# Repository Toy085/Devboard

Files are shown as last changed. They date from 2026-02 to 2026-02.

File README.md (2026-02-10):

# Info about the devboard

This devboard is bulit using the RP2040 microcontroller. It features a USB-C connector for power and data, and 16 Mbit of external flash storage.

### Images of the devboard:



### BOM:
Available in .csv format: [bom.csv](https://github.com/Toy085/Devboard/blob/main/bom.csv)

|  Item | Qty | Link |
| ---| --- | ---|
| 0.1uF Capacitor | 11 | https://jlcpcb.com/partdetail/1877-CL05B104KO5NNNC/C1525 |
| 1uF Capacitor | 2 | https://jlcpcb.com/partdetail/53938-CL05A105KA5NQNC/C52923 |
| 10uF Capacitor | 2 | https://jlcpcb.com/partdetail/20411-CL10A106KP8NNNC/C19702 |
| 33pF Capacitor | 2 | https://jlcpcb.com/partdetail/1914-0402CG330J500NT/C1562 |
| Male USB C Header | 1 | https://jlcpcb.com/partdetail/Korean_HropartsElec-TYPE_C_31_M12/C165948 |
| 1x20 pin header | 2 | https://jlcpcb.com/partdetail/51993-2_54_1_20PStraightpin/C50981 |
| 1x3 pin header | 1 | https://jlcpcb.com/partdetail/50265-2_54_13PPin/C49257 |
| RP2040 | 1 | https://jlcpcb.com/partdetail/RaspberryPi-RP2040/C2040 |
| Button | 1 | https://jlcpcb.com/partdetail/XUNPU-TS_1088AR02016/C720477 |
| 5.1K Resistor | 2 | https://jlcpcb.com/partdetail/26648-0402WGF5101TCE/C25905 |
| 1K Resistor | 2 | https://jlcpcb.com/partdetail/12256-0402WGF1001TCE/C11702 |
| 27Ω Resistor | 2 | https://jlcpcb.com/partdetail/25843-0402WGF270JTCE/C25100 |
| 10K Resistor | 1 | https://jlcpcb.com/partdetail/26487-0402WGF1002TCE/C25744 |
| 12MHz Crystal Oscillator | 1 | https://jlcpcb.com/partdetail/NDK-NX3225GA_12MHZ_STD_CRG2/C481407 |
| Transistor | 1 | https://jlcpcb.com/partdetail/2489-2SA812_RANGE_300_400/C2132 |
| Flash storage | 1 | https://jlcpcb.com/partdetail/WinbondElec-W25Q16JVUXIQ/C2843335 |

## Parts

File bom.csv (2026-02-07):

Designator | Footprint | Quantity | Value | LCSC Part #
C1, C11, C12, C17, C3, C4, C5, C6, C7, C8, C9 | 0402 | 11 | 0.1uF
C10, C2 | 0402 | 2 | 1uF
C13, C14 | 0603 | 2 | 10uF
C15, C16 | 0402 | 2 | 33pF
J1 | USB_C_Receptacle_HRO_TYPE-C-31-M-12 | 1 | USB_C_Receptacle_USB2.0_14P
J2, J3 | PinHeader_1x20_P2.54mm_Vertical | 2 | Conn_01x20
J4 | PinHeader_1x03_P2.54mm_Vertical | 1 | Conn_01x03
R1, R2 | 0402 | 2 | 5.1K
R3, R4 | 0402 | 2 | 27
R5, R6 | 0402 | 2 | 1K
R7 | 0402 | 1 | 10K
SW1 | SW_Push_SPST_NO_Alps_SKRK | 1 | SW_Push
U1 | QFN-56-1EP_7x7mm_P0.4mm_EP3.2x3.2mm | 1 | RP2040
U2 | SOT-23 | 1 | MCP1700x-330xxTT
U3 | Winbond_USON-8-1EP_3x2mm_P0.5mm_EP0.2x1.6mm | 1 | W25Q16JVZPIQ TR
Y1 | Crystal_SMD_3225-4Pin_3.2x2.5mm | 1 | 12 MHz

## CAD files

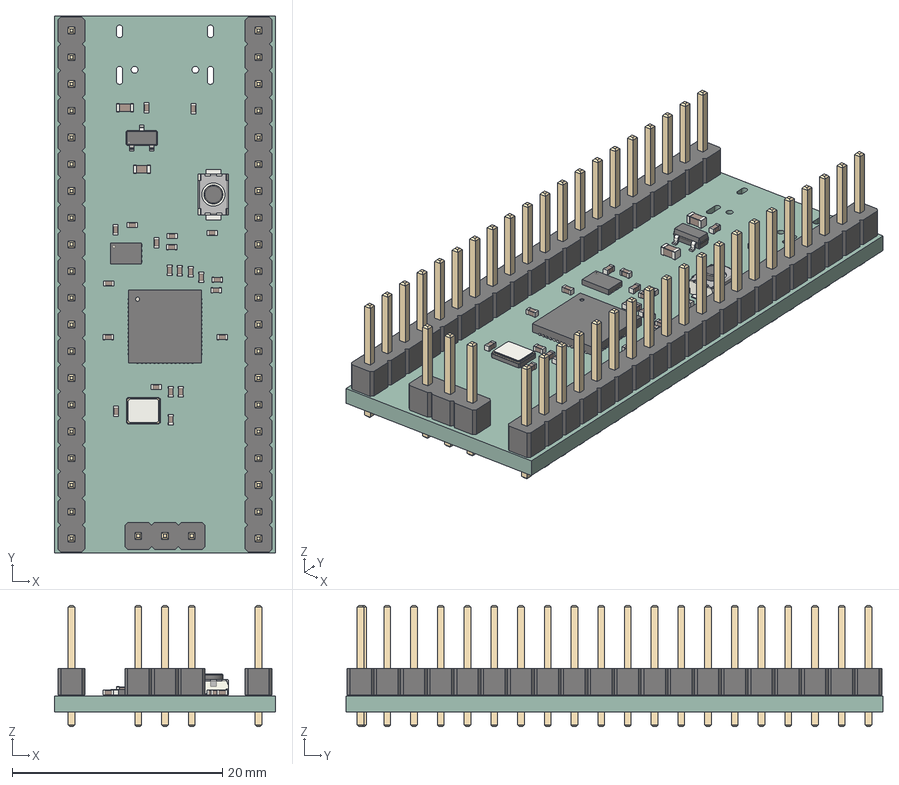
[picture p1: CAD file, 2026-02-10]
Devboard.step
21.0 x 51.0 x 11.5 mm
C_0402_1005Metric x 22
Winbond_USON-8-1EP_3x2mm_P0.5mm_EP0.2x1.6mm
QFN-56-1EP_7x7mm_P0.4mm_EP3.2x3.2mm
C_0603_1608Metric x 2
Crystal_SMD_3225-4Pin_3.2x2.5mm
PinHeader_1x20_P2.54mm_Vertical x 2
SOT-23
SW_Push_SPST_NO_Alps_SKRK
PinHeader_1x03_P2.54mm_Vertical
Devboard_PCB

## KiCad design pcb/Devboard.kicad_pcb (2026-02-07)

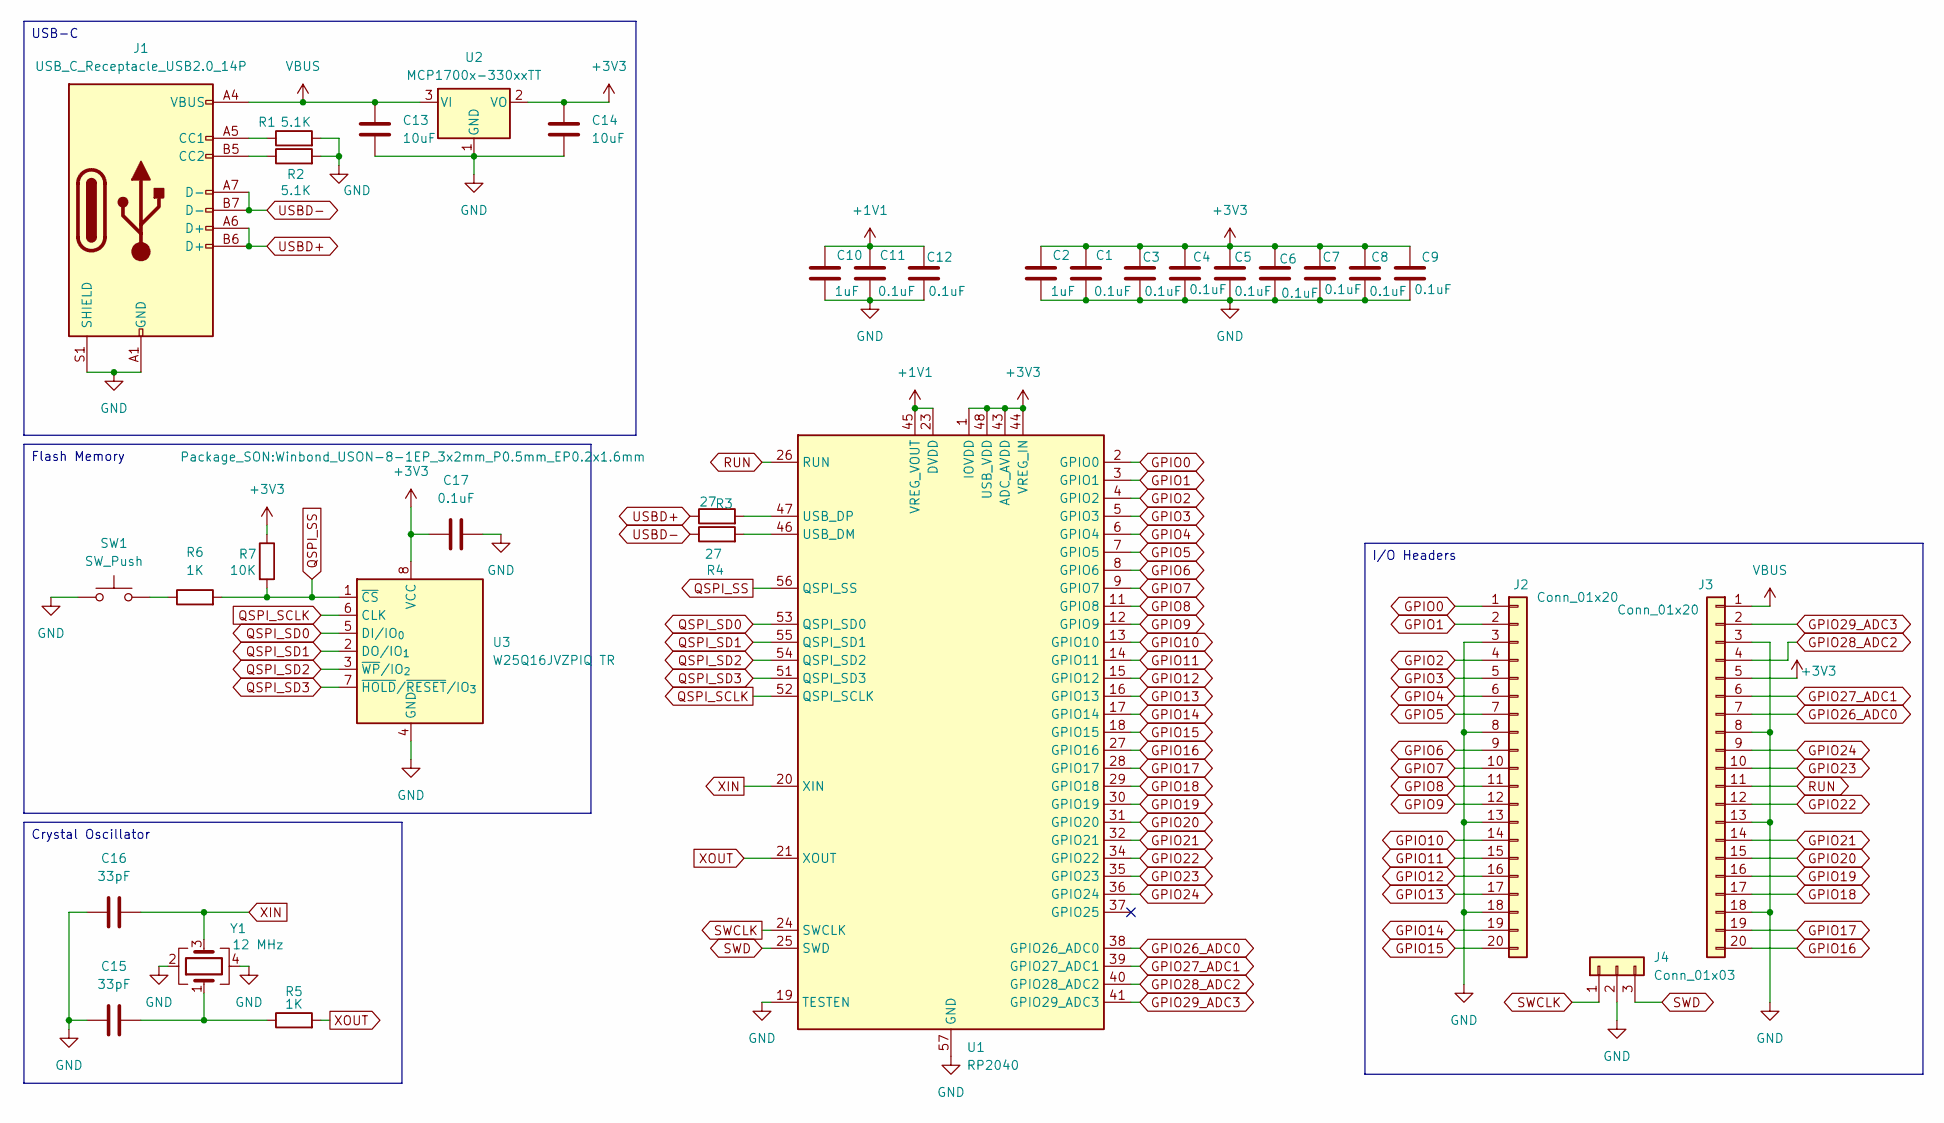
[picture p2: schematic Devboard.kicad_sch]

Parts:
C1, C3, C4, C5, C6, C7, C8, C9, C11, C12, C17: 0.1uF; C_0402_1005Metric
C2, C10: 1uF; C_0402_1005Metric
C13, C14: 10uF; C_0603_1608Metric
C15, C16: 33pF; C_0402_1005Metric
J1: USB_C_Receptacle_USB2.0_14P; USB_C_Receptacle_HRO_TYPE-C-31-M-12
J2, J3: Conn_01x20; PinHeader_1x20_P2.54mm_Vertical
J4: Conn_01x03; PinHeader_1x03_P2.54mm_Vertical
R1, R2: 5.1K; C_0402_1005Metric
R3, R4: 27; C_0402_1005Metric
R5, R6: 1K; C_0402_1005Metric
R7: 10K; C_0402_1005Metric
SW1: SW_Push; SW_Push_SPST_NO_Alps_SKRK
U1: RP2040; QFN-56-1EP_7x7mm_P0.4mm_EP3.2x3.2mm
U2: MCP1700x-330xxTT; SOT-23
U3: W25Q16JVZPIQ TR; Winbond_USON-8-1EP_3x2mm_P0.5mm_EP0.2x1.6mm
Y1: 12 MHz; Crystal_SMD_3225-4Pin_3.2x2.5mm

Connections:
+1V1: C10.1, C11.1, C12.1, U1.23 (DVDD), U1.45 (VREG_VOUT), U1.50 (DVDD)
+3V3: C1.1, C2.1, C3.1, C4.1, C5.1, C6.1, C7.1, C8.1, C9.1, C14.1, C17.1, J3.5, R7.1, U1.1 (IOVDD), U1.10 (IOVDD), U1.22 (IOVDD), U1.33 (IOVDD), U1.42 (IOVDD), U1.43 (ADC_AVDD), U1.44 (VREG_IN), U1.48 (USB_VDD), U1.49 (IOVDD), U2.2 (VO), U3.8 (VCC)
GND: C1.2, C2.2, C3.2, C4.2, C5.2, C6.2, C7.2, C8.2, C9.2, C10.2, C11.2, C12.2, C13.2, C14.2, C15.1, C16.1, C17.2, J1.A1 (GND), J1.A12 (GND), J1.B1 (GND), J1.B12 (GND), J1.S1 (SHIELD), J2.3, J2.8, J2.13, J2.18, J3.3, J3.8, J3.13, J3.18, J4.2, R1.2, R2.2, SW1.1, U1.19 (TESTEN), U1.57 (GND), U2.1 (GND), U3.4 (GND), Y1.2, Y1.4
GPIO0: J2.1, U1.2 (GPIO0)
GPIO1: J2.2, U1.3 (GPIO1)
GPIO2: J2.4, U1.4 (GPIO2)
GPIO3: J2.5, U1.5 (GPIO3)
GPIO4: J2.6, U1.6 (GPIO4)
GPIO5: J2.7, U1.7 (GPIO5)
GPIO6: J2.9, U1.8 (GPIO6)
GPIO7: J2.10, U1.9 (GPIO7)
GPIO8: J2.11, U1.11 (GPIO8)
GPIO9: J2.12, U1.12 (GPIO9)
GPIO10: J2.14, U1.13 (GPIO10)
GPIO11: J2.15, U1.14 (GPIO11)
GPIO12: J2.16, U1.15 (GPIO12)
GPIO13: J2.17, U1.16 (GPIO13)
GPIO14: J2.19, U1.17 (GPIO14)
GPIO15: J2.20, U1.18 (GPIO15)
GPIO16: J3.20, U1.27 (GPIO16)
GPIO17: J3.19, U1.28 (GPIO17)
GPIO18: J3.17, U1.29 (GPIO18)
GPIO19: J3.16, U1.30 (GPIO19)
GPIO20: J3.15, U1.31 (GPIO20)
GPIO21: J3.14, U1.32 (GPIO21)
GPIO22: J3.12, U1.34 (GPIO22)
GPIO23: J3.10, U1.35 (GPIO23)
GPIO24: J3.9, U1.36 (GPIO24)
GPIO26_ADC0: J3.7, U1.38 (GPIO26_ADC0)
GPIO27_ADC1: J3.6, U1.39 (GPIO27_ADC1)
GPIO28_ADC2: J3.4, U1.40 (GPIO28_ADC2)
GPIO29_ADC3: J3.2, U1.41 (GPIO29_ADC3)
unnamed: C15.2, R5.1, Y1.1
unnamed: J1.A5 (CC1), R1.1
unnamed: J1.B5 (CC2), R2.1
unnamed: R6.1, SW1.2
unnamed: R4.2, U1.46 (USB_DM)
unnamed: R3.2, U1.47 (USB_DP)
QSPI_SCLK: U1.52 (QSPI_SCLK), U3.6 (CLK)
QSPI_SD0: U1.53 (QSPI_SD0), U3.5 (DI/IO_{0})
QSPI_SD1: U1.55 (QSPI_SD1), U3.2 (DO/IO_{1})
QSPI_SD2: U1.54 (QSPI_SD2), U3.3 (~WP/IO_{2})
QSPI_SD3: U1.51 (QSPI_SD3), U3.7 (~HOLD/~RESET/IO_{3})
QSPI_SS: R6.2, R7.2, U1.56 (QSPI_SS), U3.1 (~CS)
RUN: J3.11, U1.26 (RUN)
SWCLK: J4.1, U1.24 (SWCLK)
SWD: J4.3, U1.25 (SWD)
USBD+: J1.A6 (D+), J1.B6 (D+), R3.1
USBD-: J1.A7 (D-), J1.B7 (D-), R4.1
VBUS: C13.1, J1.A4 (VBUS), J1.A9 (VBUS), J1.B4 (VBUS), J1.B9 (VBUS), J3.1, U2.3 (VI)
XIN: C16.2, U1.20 (XIN), Y1.3
XOUT: R5.2, U1.21 (XOUT)

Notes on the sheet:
Flash Memory
I/O Headers
Crystal Oscillator
USB-C

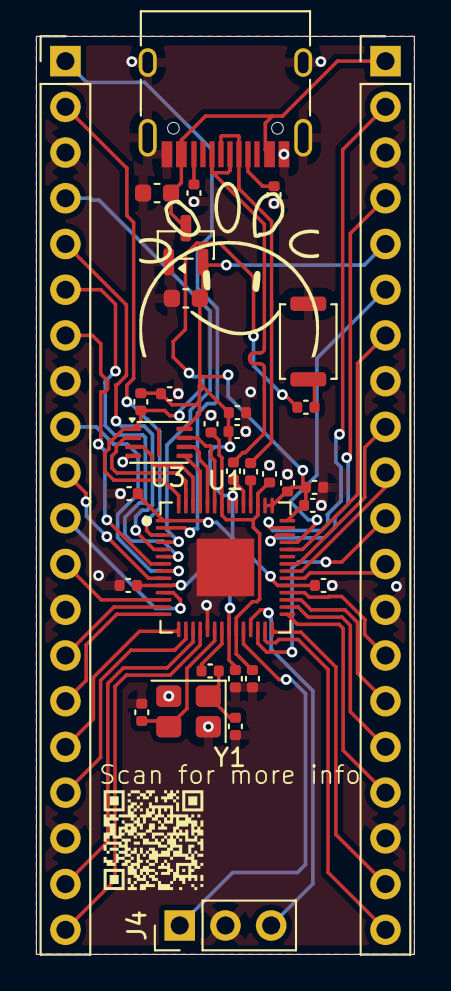
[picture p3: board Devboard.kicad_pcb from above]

Board: 2 copper layers, 21.0 x 51.0 mm, 33 parts (0 on the bottom side), 52 nets.

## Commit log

2026-02-07 Add BOM section to README
2026-02-07 Change BOM header format in README
2026-02-10 Update README structure and add BOM link
    Reorganized sections to place images before BOM and added link to BOM in CSV format.
2026-02-10 Add BOM table to README
    Added a BOM table with component details and links.
2026-02-10 Update README with new components and links
    Added additional components including buttons and resistors with their respective links.
